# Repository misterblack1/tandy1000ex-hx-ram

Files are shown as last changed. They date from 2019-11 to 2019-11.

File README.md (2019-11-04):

Tandy 1000 EX/HX RAM Expansion Board by Adrian Black. Cheap and simple, only requires 4 IC's (3 if you choose to bypass the 74LS245 with jumper links.)

You can leave off the LED and R3 if you don't want the LED. This is tested in both the Tandy 1000 EX and HX machines. If you use 74HCT logic, you can substitute 10k resistors for R1 and R2.

See the video about the board at:
https://www.youtube.com/watch?v=l3RWOZX58A8

Uploaded files here are version 1.2 of the design with the fixes applied that I talked about on the video.

Notes:
Created in KiCad v5.1.4-1

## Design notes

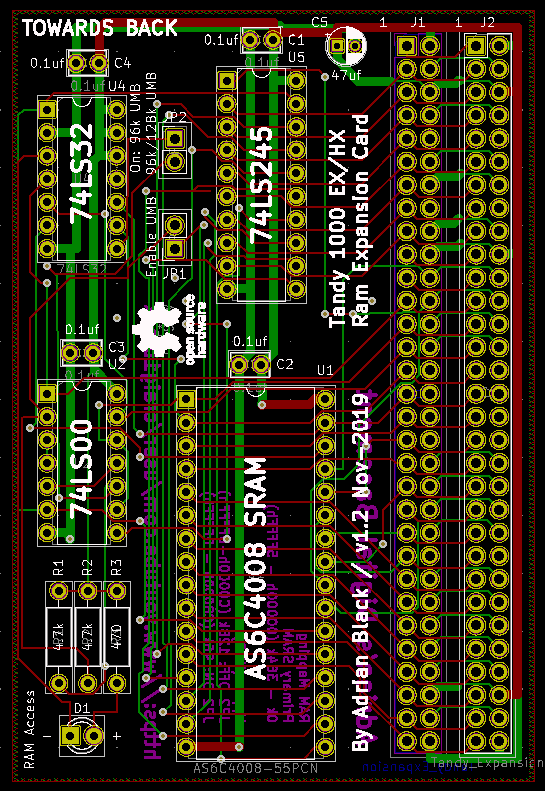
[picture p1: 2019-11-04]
Tandy PCB.png

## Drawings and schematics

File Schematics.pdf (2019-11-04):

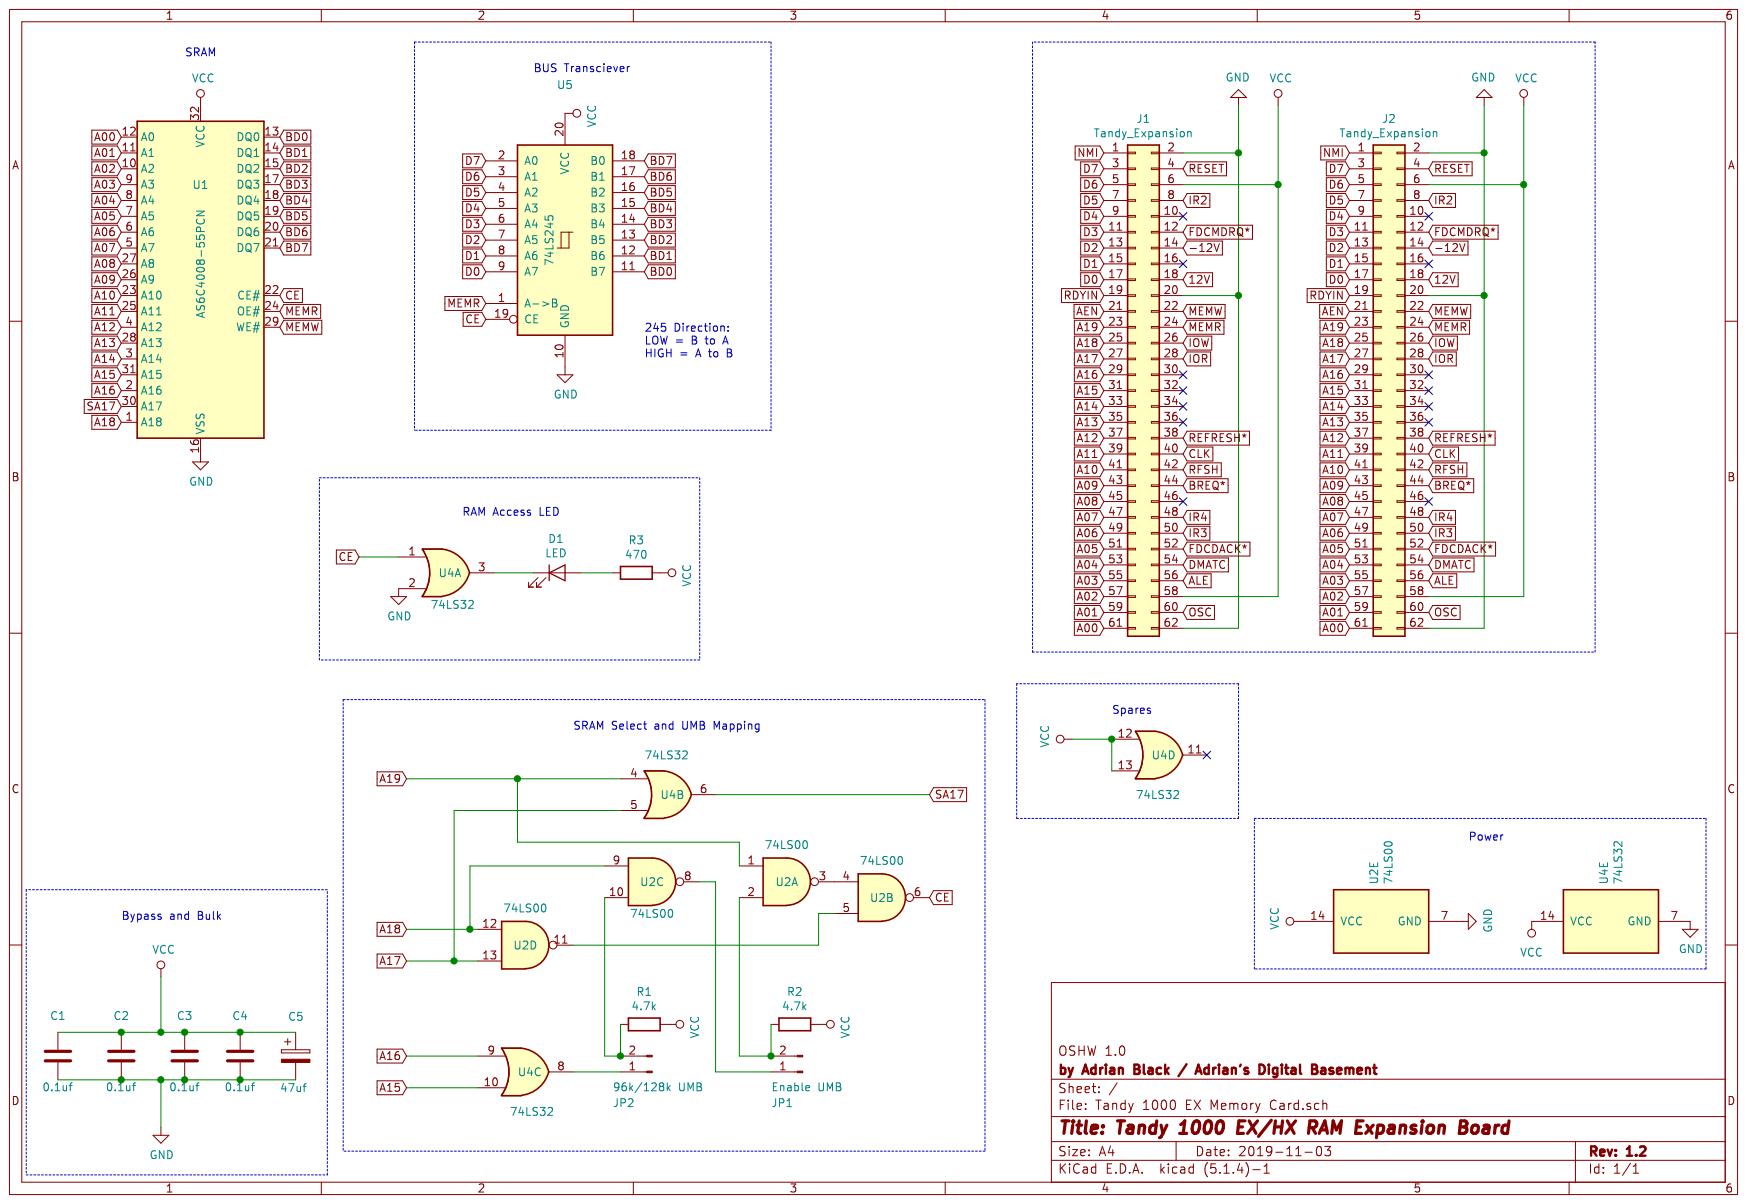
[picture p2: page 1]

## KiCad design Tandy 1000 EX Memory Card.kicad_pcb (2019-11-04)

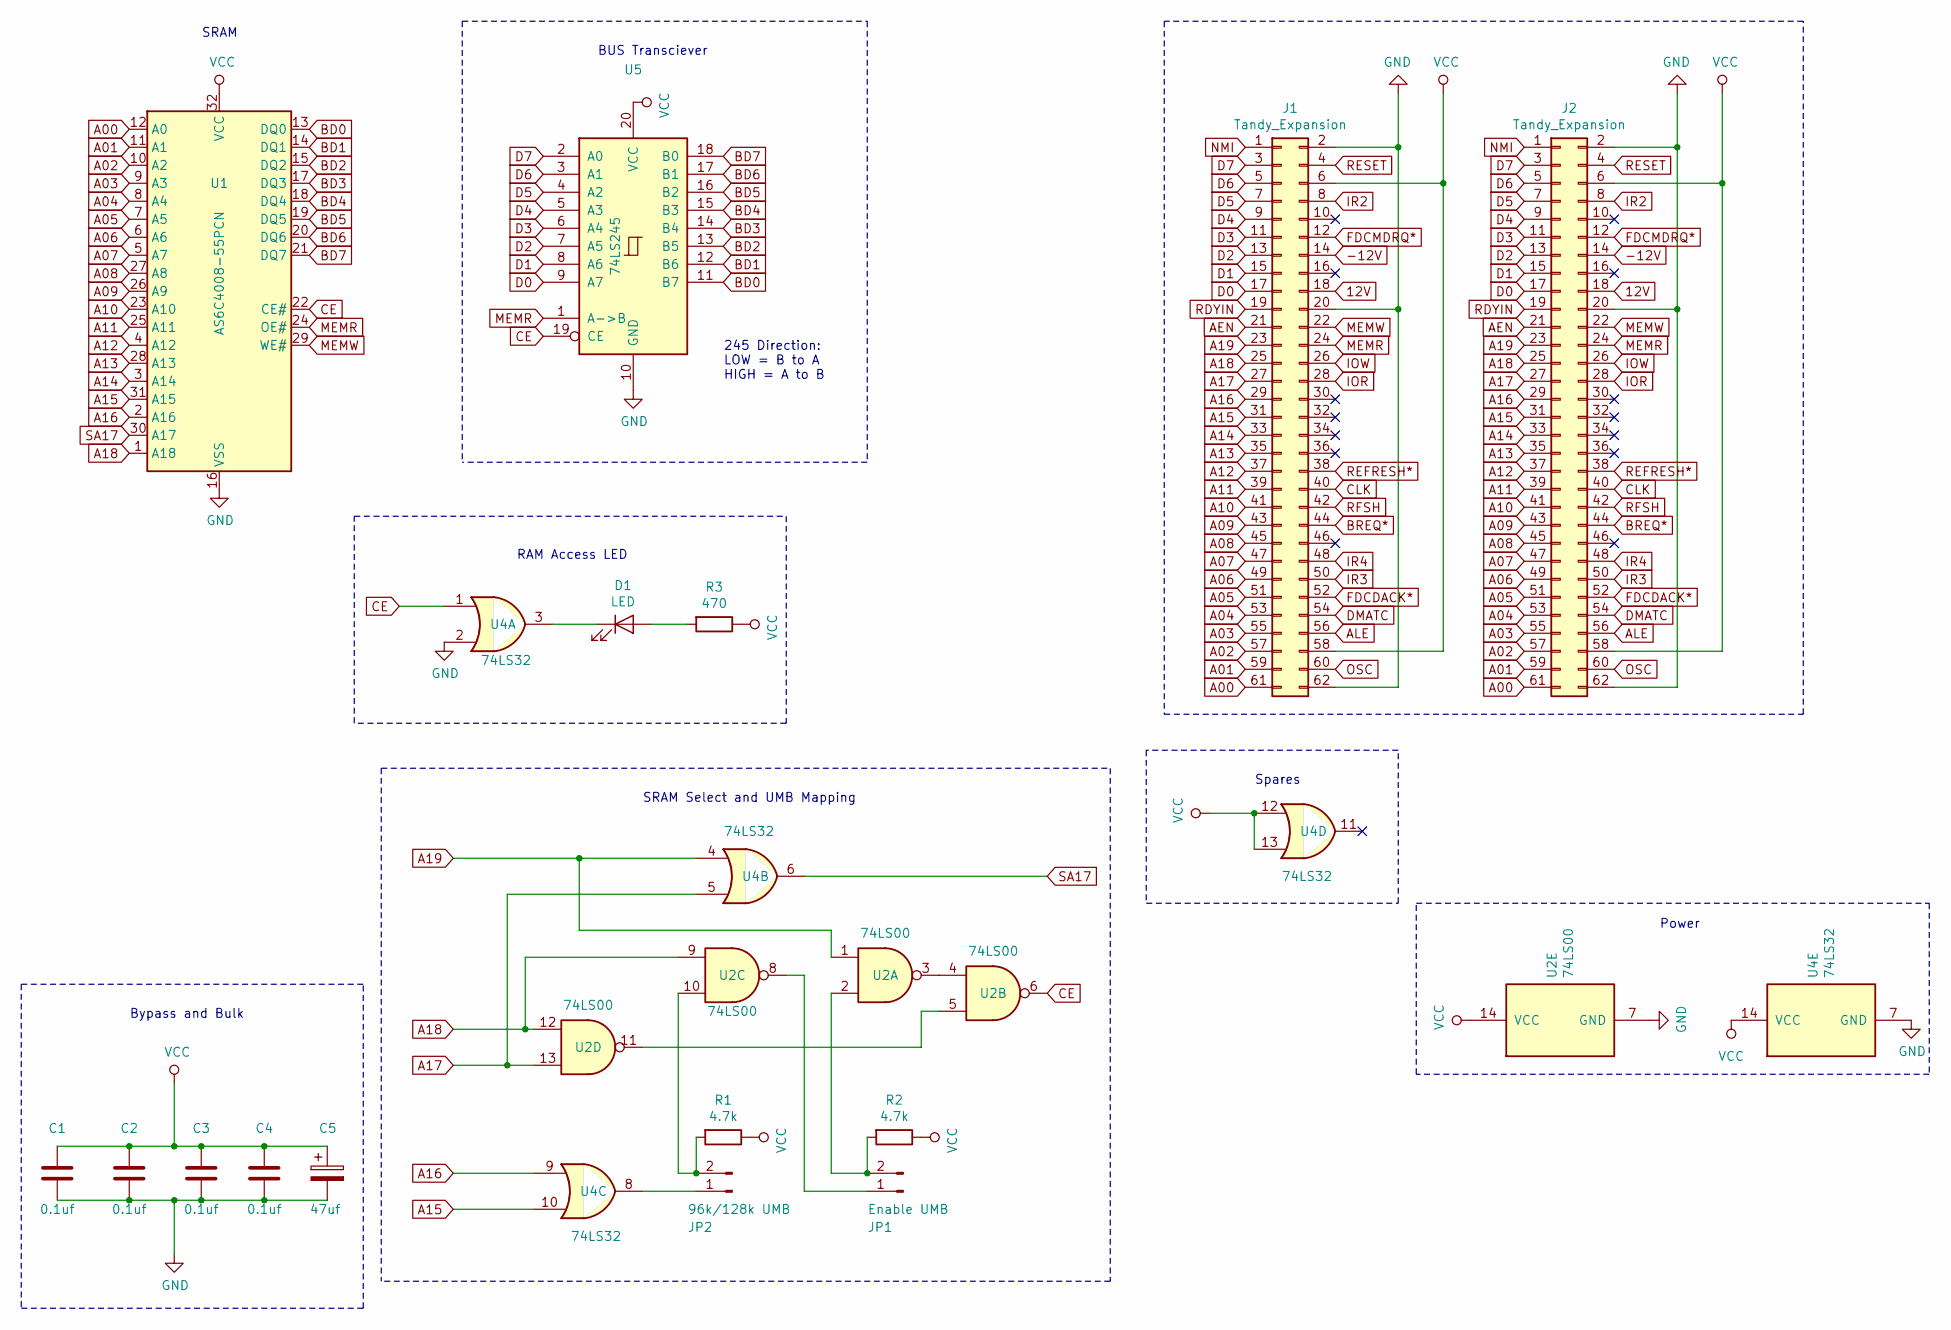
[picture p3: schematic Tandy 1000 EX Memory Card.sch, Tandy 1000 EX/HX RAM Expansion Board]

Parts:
C1, C2, C3, C4: 0.1uf; C_Rect_L4.0mm_W2.5mm_P2.50mm
C5: 47uf; CP_Radial_D4.0mm_P2.00mm
D1: LED; LED_D3.0mm
J1: Tandy_Expansion; PinSocket_2x31_P2.54mm_Vertical
J2: Tandy_Expansion; PinHeader_2x31_P2.54mm_Vertical
JP1: Enable UMB; PinSocket_1x02_P2.54mm_Vertical
JP2: 96k/128k UMB; PinHeader_1x02_P2.54mm_Vertical
R1, R2: 4.7k; R_Axial_DIN0207_L6.3mm_D2.5mm_P10.16mm_Horizontal
R3: 470; R_Axial_DIN0207_L6.3mm_D2.5mm_P10.16mm_Horizontal
U1: AS6C4008-55PCN; DIP-32_W15.24mm
U2: 74LS00; DIP-14_W7.62mm
U4: 74LS32; DIP-14_W7.62mm
U5: 74LS245; DIP-20_W7.62mm

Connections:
12V: J1.18, J2.18
-12V: J1.14, J2.14
A00: J1.61, J2.61, U1.12 (A0)
A01: J1.59, J2.59, U1.11 (A1)
A02: J1.57, J2.57, U1.10 (A2)
A03: J1.55, J2.55, U1.9 (A3)
A04: J1.53, J2.53, U1.8 (A4)
A05: J1.51, J2.51, U1.7 (A5)
A06: J1.49, J2.49, U1.6 (A6)
A07: J1.47, J2.47, U1.5 (A7)
A08: J1.45, J2.45, U1.27 (A8)
A09: J1.43, J2.43, U1.26 (A9)
A10: J1.41, J2.41, U1.23 (A10)
A11: J1.39, J2.39, U1.25 (A11)
A12: J1.37, J2.37, U1.4 (A12)
A13: J1.35, J2.35, U1.28 (A13)
A14: J1.33, J2.33, U1.3 (A14)
A15: J1.31, J2.31, U1.31 (A15), U4.10
A16: J1.29, J2.29, U1.2 (A16), U4.9
A17: J1.27, J2.27, U2.13, U4.5
A18: J1.25, J2.25, U1.1 (A18), U2.9, U2.12
A19: J1.23, J2.23, U2.1, U4.4
AEN: J1.21, J2.21
ALE: J1.56, J2.56
BD0: U1.13 (DQ0), U5.11 (B7)
BD1: U1.14 (DQ1), U5.12 (B6)
BD2: U1.15 (DQ2), U5.13 (B5)
BD3: U1.17 (DQ3), U5.14 (B4)
BD4: U1.18 (DQ4), U5.15 (B3)
BD5: U1.19 (DQ5), U5.16 (B2)
BD6: U1.20 (DQ6), U5.17 (B1)
BD7: U1.21 (DQ7), U5.18 (B0)
BREQ*: J1.44, J2.44
CE: U1.22 (CE#), U2.6, U4.1, U5.19 (CE)
CLK: J1.40, J2.40
D0: J1.17, J2.17, U5.9 (A7)
D1: J1.15, J2.15, U5.8 (A6)
D2: J1.13, J2.13, U5.7 (A5)
D3: J1.11, J2.11, U5.6 (A4)
D4: J1.9, J2.9, U5.5 (A3)
D5: J1.7, J2.7, U5.4 (A2)
D6: J1.5, J2.5, U5.3 (A1)
D7: J1.3, J2.3, U5.2 (A0)
DMATC: J1.54, J2.54
FDCDACK*: J1.52, J2.52
FDCMDRQ*: J1.12, J2.12
GND: C1.1, C2.1, C3.1, C4.1, C5.2, J1.2, J1.20, J1.62, J2.2, J2.20, J2.62, U1.16 (VSS), U2.7 (GND), U4.2, U4.7 (GND), U5.10 (GND)
IOR: J1.28, J2.28
IOW: J1.26, J2.26
IR2: J1.8, J2.8
IR3: J1.50, J2.50
IR4: J1.48, J2.48
MEMR: J1.24, J2.24, U1.24 (OE#), U5.1 (A->B)
MEMW: J1.22, J2.22, U1.29 (WE#)
NMI: J1.1, J2.1
unnamed: D1.1 (K), U4.3
unnamed: D1.2 (A), R3.2
unnamed: JP1.1, U2.8
unnamed: JP1.2, R2.2, U2.2
unnamed: JP2.1, U4.8
unnamed: JP2.2, R1.2, U2.10
unnamed: U2.3, U2.4
unnamed: U2.5, U2.11
OSC: J1.60, J2.60
RDYIN: J1.19, J2.19
REFRESH*: J1.38, J2.38
RESET: J1.4, J2.4
RFSH: J1.42, J2.42
SA17: U1.30 (A17), U4.6
VCC: C1.2, C2.2, C3.2, C4.2, C5.1, J1.6, J1.58, J2.6, J2.58, R1.1, R2.1, R3.1, U1.32 (VCC), U2.14 (VCC), U4.12, U4.13, U4.14 (VCC), U5.20 (VCC)

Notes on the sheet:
245 Direction: LOW = B to A HIGH = A to B
RAM Access LED
Spares
Power
Bypass and Bulk
SRAM
BUS Transciever
SRAM Select and UMB Mapping

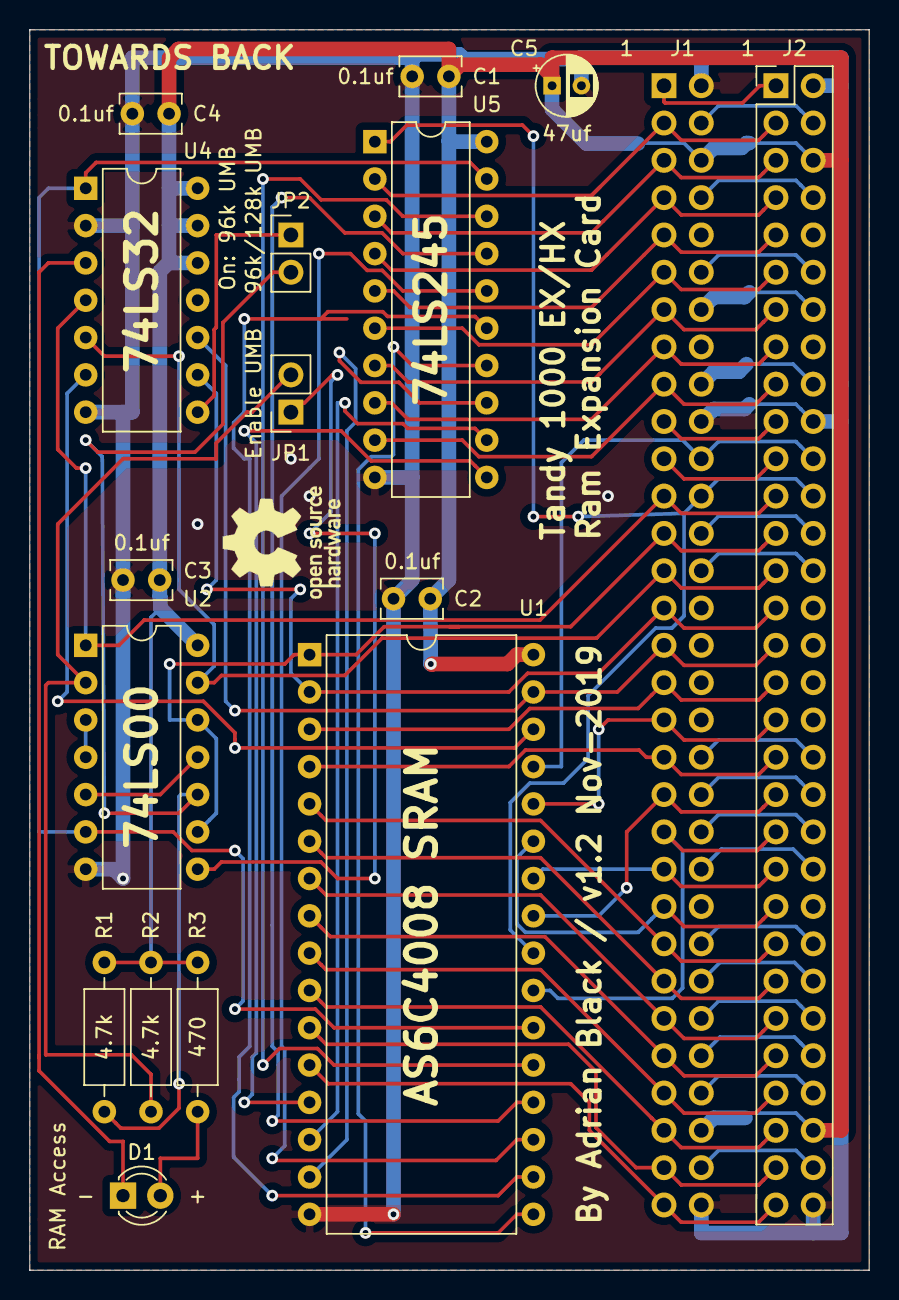
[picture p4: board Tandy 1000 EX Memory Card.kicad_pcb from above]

Board: 2 copper layers, 57.2 x 84.5 mm, 17 parts (1 on the bottom side), 70 nets.
